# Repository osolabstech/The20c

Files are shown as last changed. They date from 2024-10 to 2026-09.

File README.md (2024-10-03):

Bienvenidos a la 20c!!!

Con cada nuevo capítulo van a poder encontrar aqui todos los archivos necesarios para crear las placas de la 20c y el código para hacer los ejemplos de uso de las mismas

Welcome to the 20c!!!

With each new chapter you will find here all the files to create the 20c pcb boards and the code to follow the examples on how to use them

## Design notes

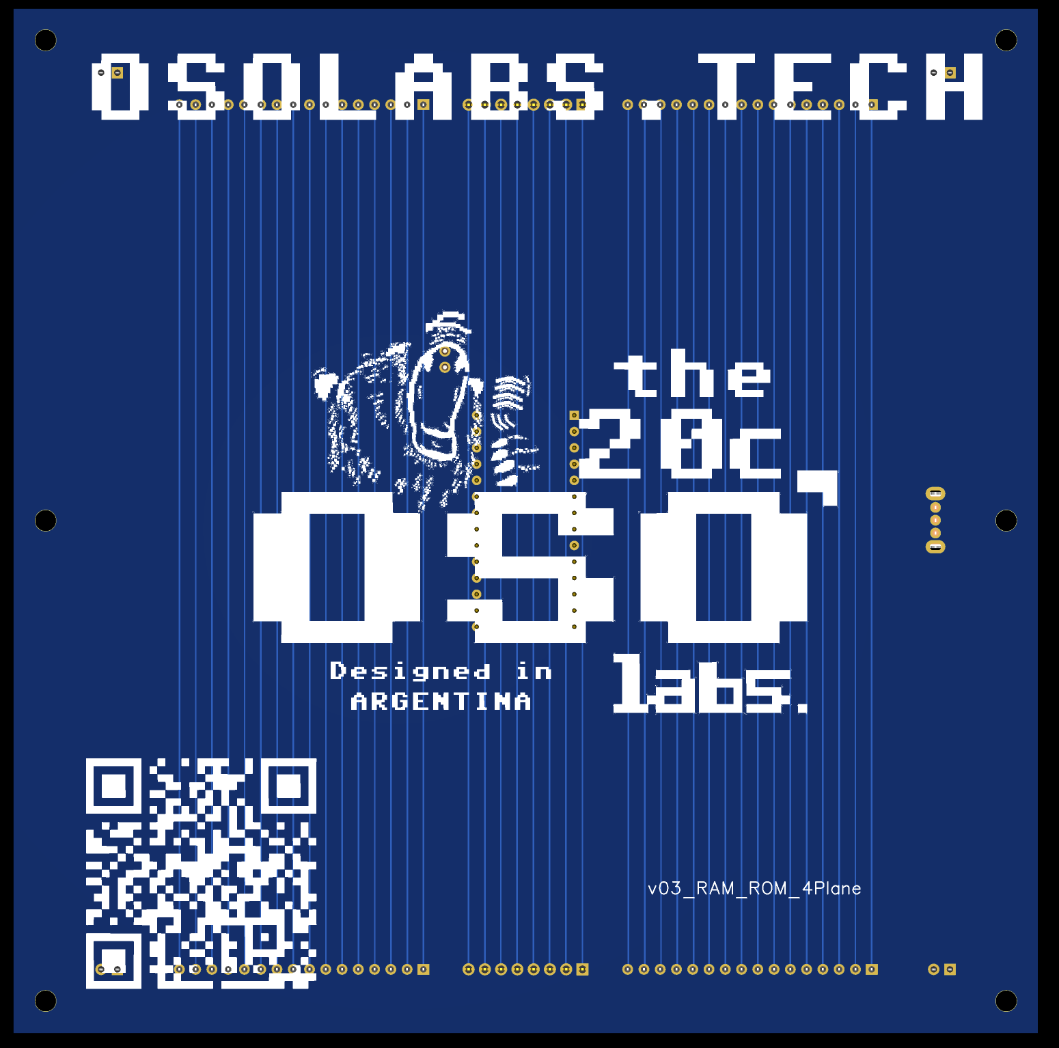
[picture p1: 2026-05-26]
Episode4_ROM/pcb/3DModel_ramrom_back.png

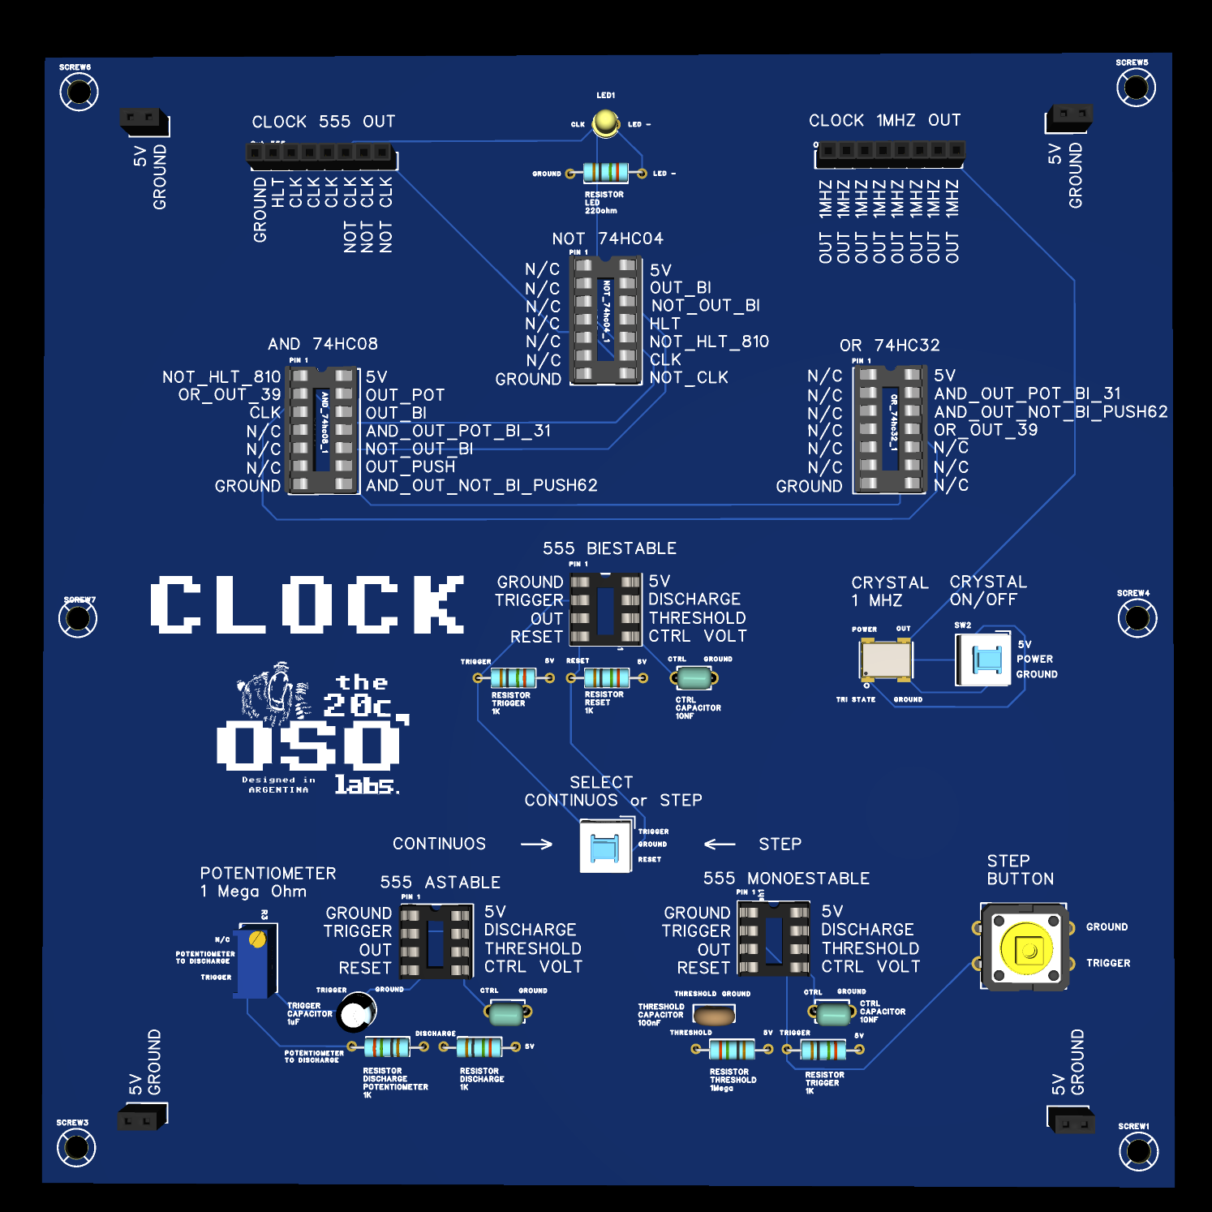
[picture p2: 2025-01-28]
Episode2_CLOCK/v03_CLOCK_4Plane/3DModel_CLOCK_FRONT.png

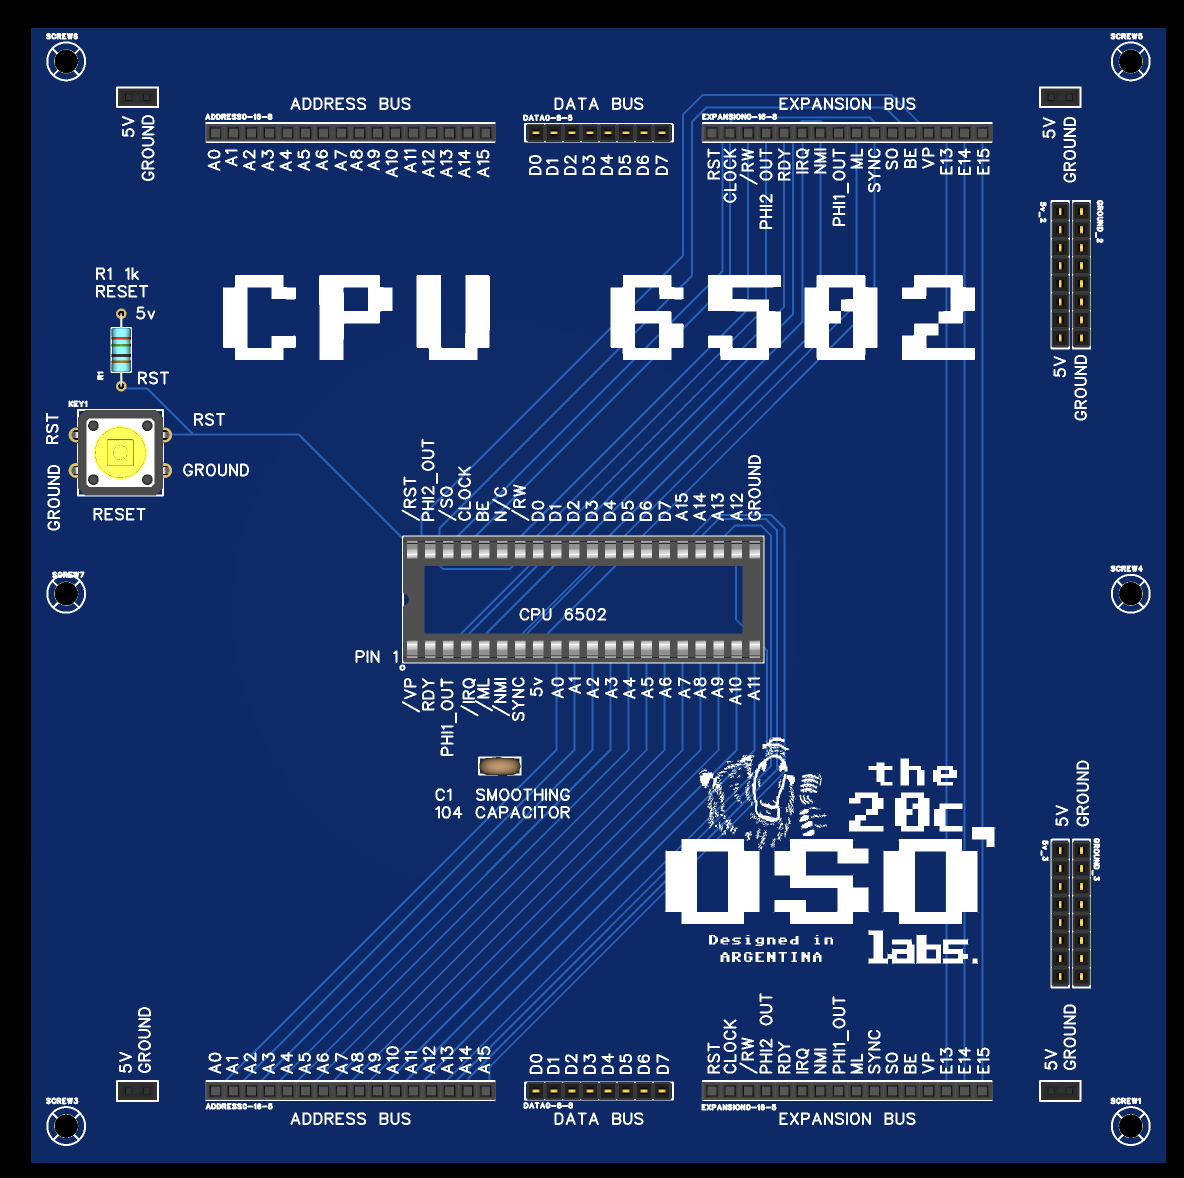
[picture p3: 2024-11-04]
Episode1_CPU6502/v03_CPU6502_4Plane/cpu6502_3dModel.png

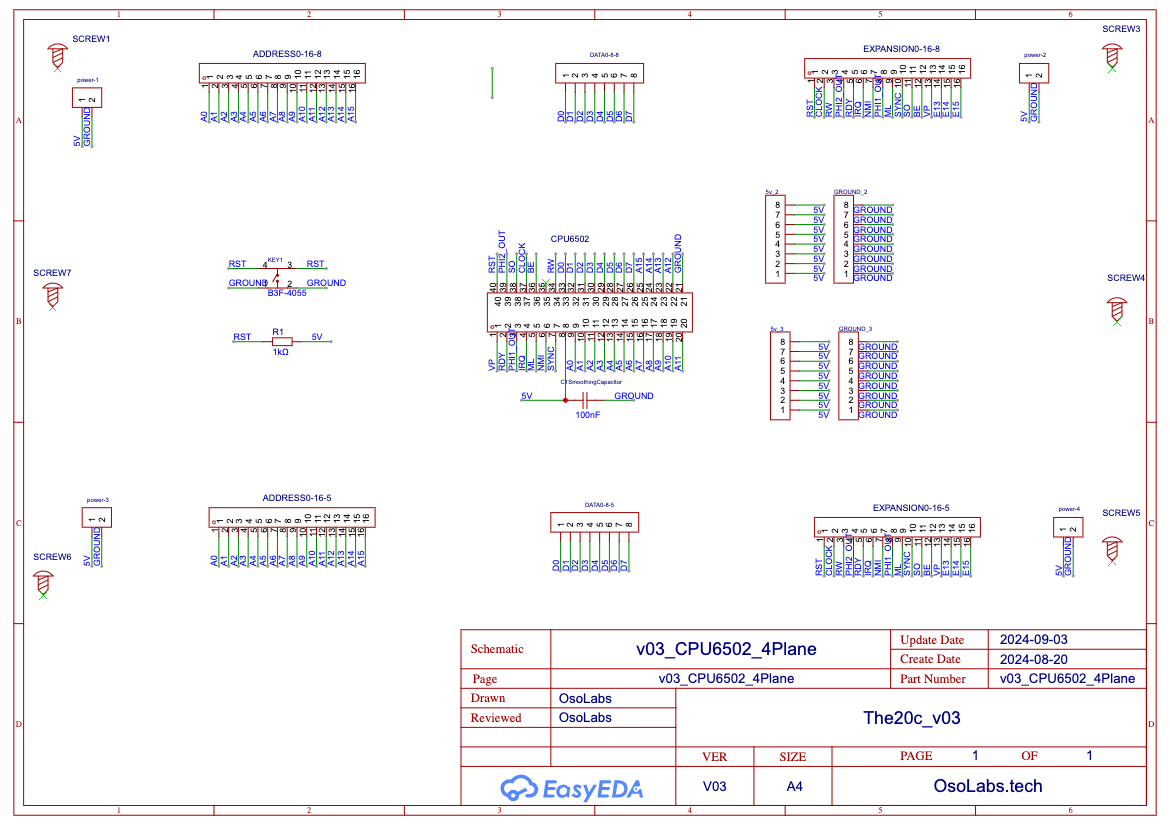
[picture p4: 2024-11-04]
Episode1_CPU6502/v03_CPU6502_4Plane/cpu6502_Circuit.png

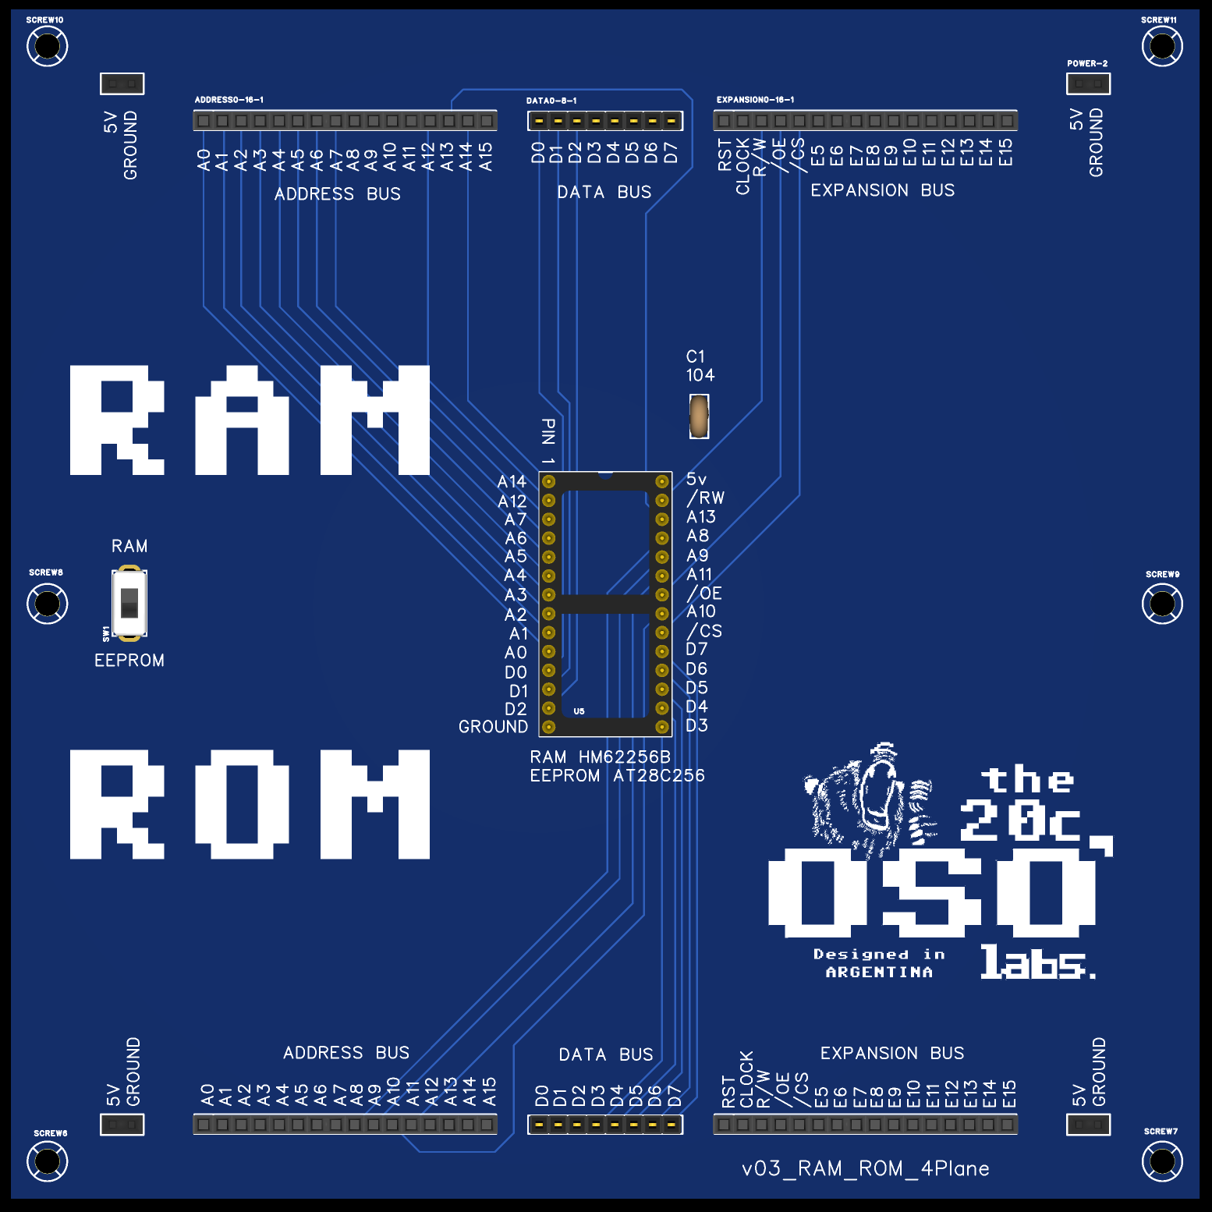
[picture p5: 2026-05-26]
Episode4_ROM/pcb/3DModel_ramrom_front.png

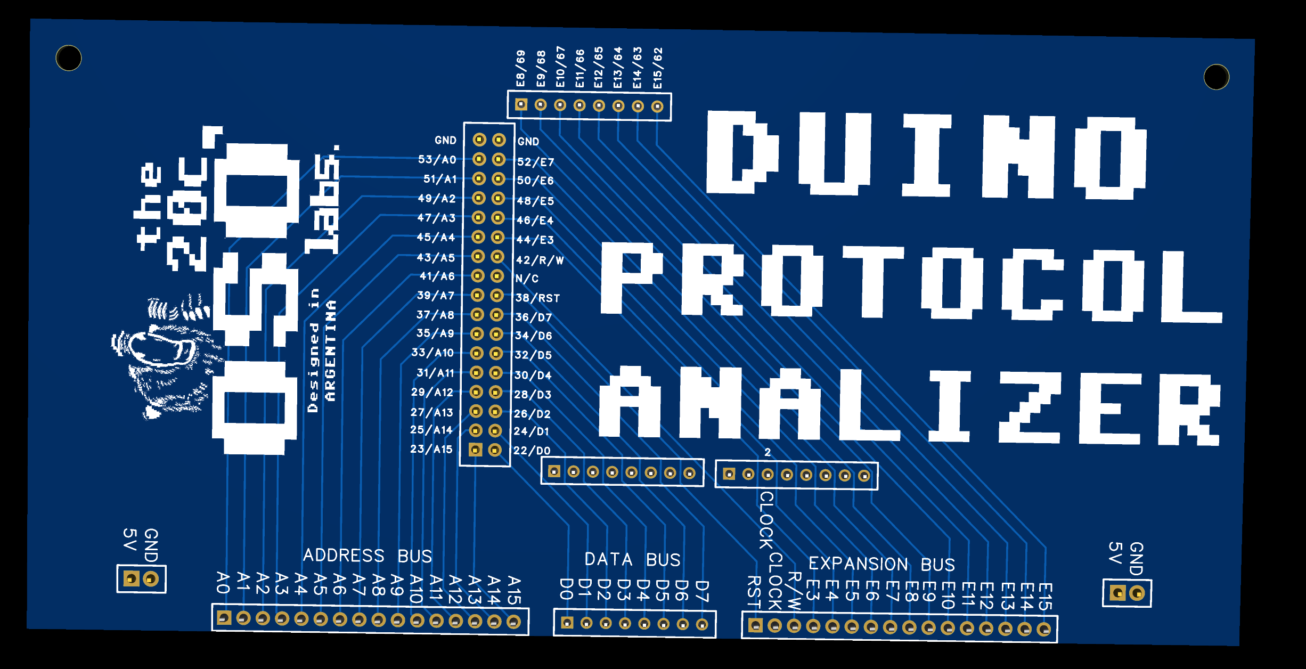
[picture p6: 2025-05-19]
Episode3_DUINO_PA/v03_PROTOCOL_ANALYZER_DUINO_4Plane/3DModel_duino_pa_back.png

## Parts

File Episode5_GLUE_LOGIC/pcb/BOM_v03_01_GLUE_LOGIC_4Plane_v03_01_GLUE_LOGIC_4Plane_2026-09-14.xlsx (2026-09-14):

No. | Quantity | Comment | Designator | Footprint | Value | Manufacturer Part | Manufacturer | Supplier Part | Supplier
1 | 12 | 2.54-1*8P母环保 | 5v_1,5v_2,5v_3,5v_4,DATA0-8-5,DATA0-8-6,DATA0-8-7,DATA0-8-8,GROUND_1,GROUND_2,GROUND_3,GROUND_4 | HDR-TH_8P-P2.54-V-F-1 |  | 2.54-1*8P母环保 | BOOMELE(博穆精密) | C27438 | LCSC
2 | 8 | PM254-1-16-Z-8.5 | ADDRESS0-16-5,ADDRESS0-16-6,ADDRESS0-16-7,ADDRESS0-16-8,EXPANSION0-16-5,EXPANSION0-16-6,EXPANSION0-16-7,EXPANSION0-16-8 | HDR-TH_16P-P2.54-V-F-A |  | PM254-1-16-Z-8.5 | HCTL(华灿天禄) | C2897379 | LCSC
3 | 4 | IC-14P窄 | AND_74hc08_1,NAND_74hc00_1,NOT_74hc04_1,OR_74hc32_1 | DIP-14_L17.8-W10.2-P2.54-BL |  | IC-14P窄 | BOOMELE(博穆精密) | C2325 | LCSC
4 | 12 | PM254-1-12-Z-8.5 | AND_HEADER,AND_HEADER1,AND_HEADER2,NAND_HEADER,NAND_HEADER1,NAND_HEADER2,NOT_HEADER,NOT_HEADER1,NOT_HEADER2,OR_HEADER,OR_HEADER1,OR_HEADER2 | HDR-TH_12P-P2.54-V-F |  | PM254-1-12-Z-8.5 | HCTL(华灿天禄) | C2897375 | LCSC
5 | 4 | 2.54-1*2P母 | power-1,power-2,power-3,power-4 | HDR-TH_2P-P2.54-V-F |  | 2.54-1*2P母 | BOOMELE(博穆精密) | C49661 | LCSC
6 | 6 | Screw-Hole-M3 | SCREW1,SCREW2,SCREW3,SCREW4,SCREW5,SCREW6 | Screw-Hole-M3

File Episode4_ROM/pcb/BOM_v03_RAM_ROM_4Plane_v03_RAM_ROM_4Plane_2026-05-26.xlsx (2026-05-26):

No. | Quantity | Comment | Designator | Footprint | Value | Manufacturer Part | Manufacturer | Supplier Part | Supplier
1 | 4 | PM254-1-16-Z-8.5 | ADDRESS0-16-1,ADDRESS0-16-2,EXPANSION0-16-1,EXPANSION0-16-2 | HDR-TH_16P-P2.54-V-F-A |  | PM254-1-16-Z-8.5 | HCTL(华灿天禄) | C2897379 | LCSC
2 | 1 | 100nF | C1SmoothingCapacitor1 | CAP-TH_L5.8-W2.4-P2.54-D0.6 | 100nF | CC1H104ZA1ED3F5P1100 | Dersonic(德尔创) | C2832506 | LCSC
3 | 2 | 2.54-1*8P母环保 | DATA0-8-1,DATA0-8-2 | HDR-TH_8P-P2.54-V-F-1 |  | 2.54-1*8P母环保 | BOOMELE(博穆精密) | C27438 | LCSC
4 | 4 | 2.54-1*2P母 | POWER-1,POWER-2,POWER-3,POWER-4 | HDR-TH_2P-P2.54-V-F |  | 2.54-1*2P母 | BOOMELE(博穆精密) | C49661 | LCSC
5 | 6 | Screw-Hole-M3 | SCREW6,SCREW7,SCREW8,SCREW9,SCREW10,SCREW11 | Screw-Hole-M3
6 | 1 | SS12D07VG4 087 | SW1 | SW-TH_SS12D07VG4 |  | SS12D07VG4 087 | SHOU HAN(首韩) | C2939726 | LCSC
7 | 1 | DS1009-28AT1WX-0A2 | U5 | DIP-28_L35.6-W17.8-P2.54-LS15.2-BL |  | DS1009-28AT1WX-0A2 | CONNFLY | C72121 | LCSC

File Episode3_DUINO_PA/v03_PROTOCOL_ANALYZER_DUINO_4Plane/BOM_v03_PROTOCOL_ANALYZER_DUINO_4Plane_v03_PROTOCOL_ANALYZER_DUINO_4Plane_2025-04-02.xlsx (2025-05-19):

No. | Quantity | Comment | Designator | Footprint | Value | Manufacturer Part | Manufacturer | Supplier Part | Supplier
1 | 4 | X6511WV-08H-C60D30 | H1,H12,H16,H18 | HDR-TH_8P-P2.54-V-M |  | X6511WV-08H-C60D30 | XKB Connection(中国星坤) | C706880 | LCSC
2 | 2 | X6511WV-16H-C60D30 | H3,H13 | HDR-TH_16P-P2.54-V-M |  | X6511WV-16H-C60D30 | XKB Connection(中国星坤) | C725948 | LCSC
3 | 2 | X6511WV-02H-C60D30 | H6,H14 | HDR-TH_2P-P2.54-V-M |  | X6511WV-02H-C60D30 | XKB Connection(中国星坤) | C706874 | LCSC
4 | 1 | PZ254-2-17-Z-8.5 | H15 | HDR-TH_34P-P2.54-V-M-R2-C17-S2.54 |  | PZ254-2-17-Z-8.5 | HCTL(华灿天禄) | C2894978 | LCSC
5 | 2 | Screw-Hole-M3 | SCREW8,SCREW9 | Screw-Hole-M3

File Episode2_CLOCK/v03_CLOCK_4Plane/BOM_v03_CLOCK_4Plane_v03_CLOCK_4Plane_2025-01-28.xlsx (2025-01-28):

No. | Quantity | Comment | Designator | Footprint | Value | Manufacturer Part | Manufacturer | Supplier Part | Supplier
1 | 3 | DS1009-08AT1NX-0A2 | 555AstablePOT,555BistableSwitch1,555MonoStablePush1 | DIP-8_L10.2-W10.2-P2.54-LS7.6-BL |  | DS1009-08AT1NX-0A2 | CONNFLY | C72124 | LCSC
2 | 3 | IC-14P窄 | AND_74hc08_1,NOT_74hc04_1,OR_74hc32_1 | DIP-14_L17.8-W10.2-P2.54-BL |  | IC-14P窄 | BOOMELE(博穆精密) | C2325 | LCSC
3 | 1 | 100nF | C1SmoothingCapacitor2 | CAP-TH_L5.8-W2.4-P2.54-D0.6 | 100nF | CC1H104ZA1ED3F5P1100 | Dersonic(德尔创) | C2832506 | LCSC
4 | 1 | 1uF | C2 | CAP-TH_BD5.0-P2.00-D0.8-FD | 1uF | KF010M050C110A | CapXon(丰宾) | C62934 | LCSC
5 | 1 | B3F-4055 | KEY1 | KEY-TH_4P-L12.0-W12.0-P5.00-LS13.4-EH |  | B3F-4055 | OMRON(欧姆龙) | C84931 | LCSC
6 | 1 | XL-302UYD | LED1 | LED-TH_BD3.8-P2.54-FD_YELLOW |  | XL-302UYD | XINGLIGHT(成兴光) | C2895472 | LCSC
7 | 2 | 2.54-1*8P母环保 | OUT_1MHZ,Out_555 | HDR-TH_8P-P2.54-V-F-1 |  | 2.54-1*8P母环保 | BOOMELE(博穆精密) | C27438 | LCSC
8 | 4 | 2.54-1*2P母 | power-1,power-2,power-3,power-4 | HDR-TH_2P-P2.54-V-F |  | 2.54-1*2P母 | BOOMELE(博穆精密) | C49661 | LCSC
9 | 5 | 1kΩ | R1,R4,R5,R10,R12 | RES-TH_BD2.7-L6.2-P10.20-D0.4 | 1kΩ | CR1/4W-1K±5%-ST26 | VO(翔胜) | C2894606 | LCSC
10 | 1 | 220Ω | R2 | RES-TH_BD2.7-L6.2-P10.20-D0.4 | 220Ω | CR1/4W-220Ω±5%-ST26 | VO(翔胜) | C2894616 | LCSC
11 | 1 | 1MΩ | R3 | RES-ADJ-TH_3296W | 1MΩ | 3296W-1-105-8mm | BOCHEN(博晨) | C330438 | LCSC
12 | 1 | 1MΩ | R9 | RES-TH_BD2.7-L6.2-P10.20-D0.4 | 1MΩ | CR1/4W-1M±5%-ST52 | VO(翔胜) | C2894664 | LCSC
13 | 6 | Screw-Hole-M3 | SCREW1,SCREW3,SCREW4,SCREW5,SCREW6,SCREW7 | Screw-Hole-M3
14 | 2 | XKB7070-Z | SW1,SW2 | SW-TH_6P-L7.0-W7.0-P2.00 |  | XKB7070-Z | XKB Connectivity(中国星坤) | C318863 | LCSC
15 | 3 | 10nF | U4,U5,U6 | CAP-TH_L4.8-W3.2-P5.08-D1.2 | 10nF | CC1H103ZC1ED3F4D1100 | Dersonic(德尔创) | C2761727 | LCSC
16 | 1 | 1MHz | X1 | OSC-SMD_4P-L7.0-W5.0-BL_7W16070003 | 1MHz | S7D1.000000A20F30T | SCTF(星通时频) | C386887 | LCSC

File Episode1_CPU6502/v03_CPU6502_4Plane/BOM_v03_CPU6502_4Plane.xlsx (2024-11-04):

No. | Quantity | Comment | Designator | Footprint | Value | Manufacturer Part | Manufacturer | Supplier Part | Supplier
1 | 6 | 2.54-1*8P母环保 | 5v_2,5v_3,DATA0-8-5,DATA0-8-8,GROUND_2,GROUND_3 | HDR-TH_8P-P2.54-V-F-1 |  | 2.54-1*8P母环保 | BOOMELE(博穆精密) | C27438 | LCSC
2 | 4 | PM254-1-16-Z-8.5 | ADDRESS0-16-5,ADDRESS0-16-8,EXPANSION0-16-5,EXPANSION0-16-8 | HDR-TH_16P-P2.54-V-F-A |  | PM254-1-16-Z-8.5 | HCTL(华灿天禄) | C2897379 | LCSC
3 | 1 | 100nF | C1SmoothingCapacitor | CAP-TH_L5.8-W2.4-P2.54-D0.6 | 100nF | CC1H104ZA1ED3F5P1100 | Dersonic(德尔创) | C2832506 | LCSC
4 | 1 | IC座-40P | CPU6502 | DIP-40_L50.8-W17.8-P2.54-LS15.2-BL |  | IC座-40P | BOOMELE(博穆精密) | C2332 | LCSC
5 | 1 | B3F-4055 | KEY1 | KEY-TH_4P-L12.0-W12.0-P5.00-LS13.4-EH |  | B3F-4055 | OMRON(欧姆龙) | C84931 | LCSC
6 | 4 | 2.54-1*2P母 | power-1,power-2,power-3,power-4 | HDR-TH_2P-P2.54-V-F |  | 2.54-1*2P母 | BOOMELE(博穆精密) | C49661 | LCSC
7 | 1 | 1kΩ | R1 | RES-TH_BD2.7-L6.2-P10.20-D0.4 | 1kΩ | CR1/4W-1K±5%-ST26 | VO(翔胜) | C2894606 | LCSC
8 | 6 | Screw-Hole-M3 | SCREW1,SCREW3,SCREW4,SCREW5,SCREW6,SCREW7 | Screw-Hole-M3

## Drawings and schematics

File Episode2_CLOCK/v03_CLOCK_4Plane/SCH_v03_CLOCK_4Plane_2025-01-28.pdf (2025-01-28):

# Adjustable Clock

# Input / Output

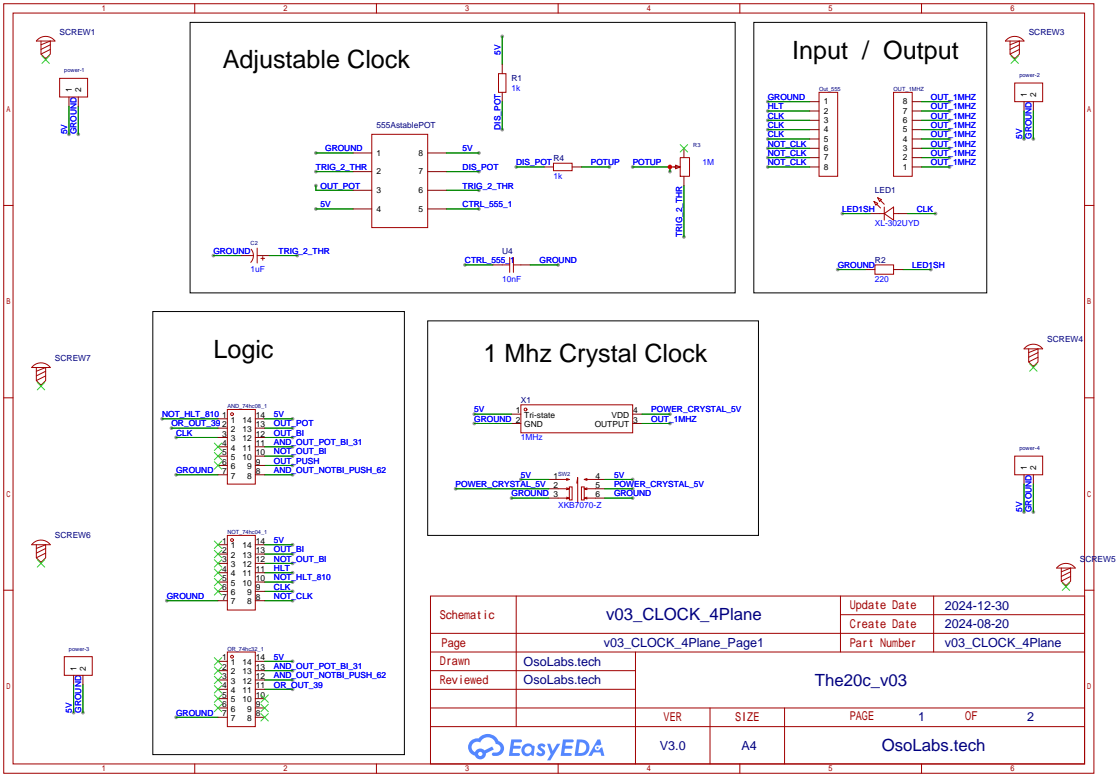
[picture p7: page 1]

Step by Step Clock | Button Debouncing

# GROUND⁵V

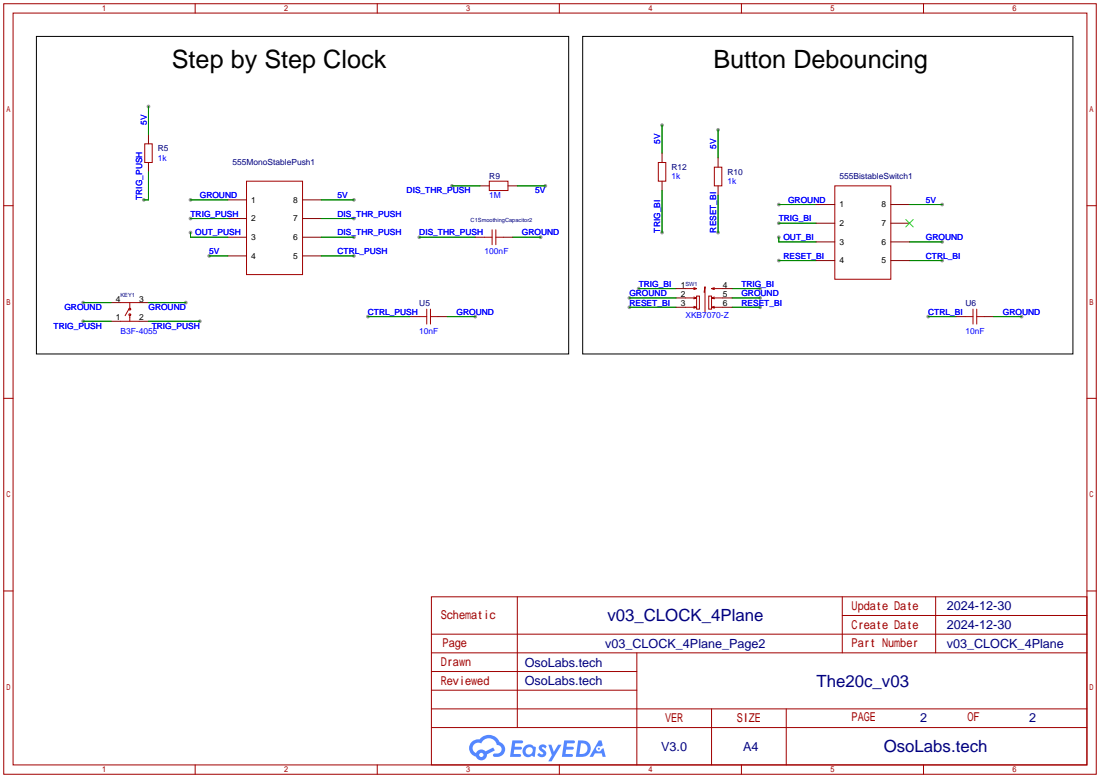
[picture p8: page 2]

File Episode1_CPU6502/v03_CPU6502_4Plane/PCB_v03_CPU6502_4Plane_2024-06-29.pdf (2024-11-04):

ADDRESS BUS | DATA BUS | EXPANSION BUS
R1 | 1k RESET

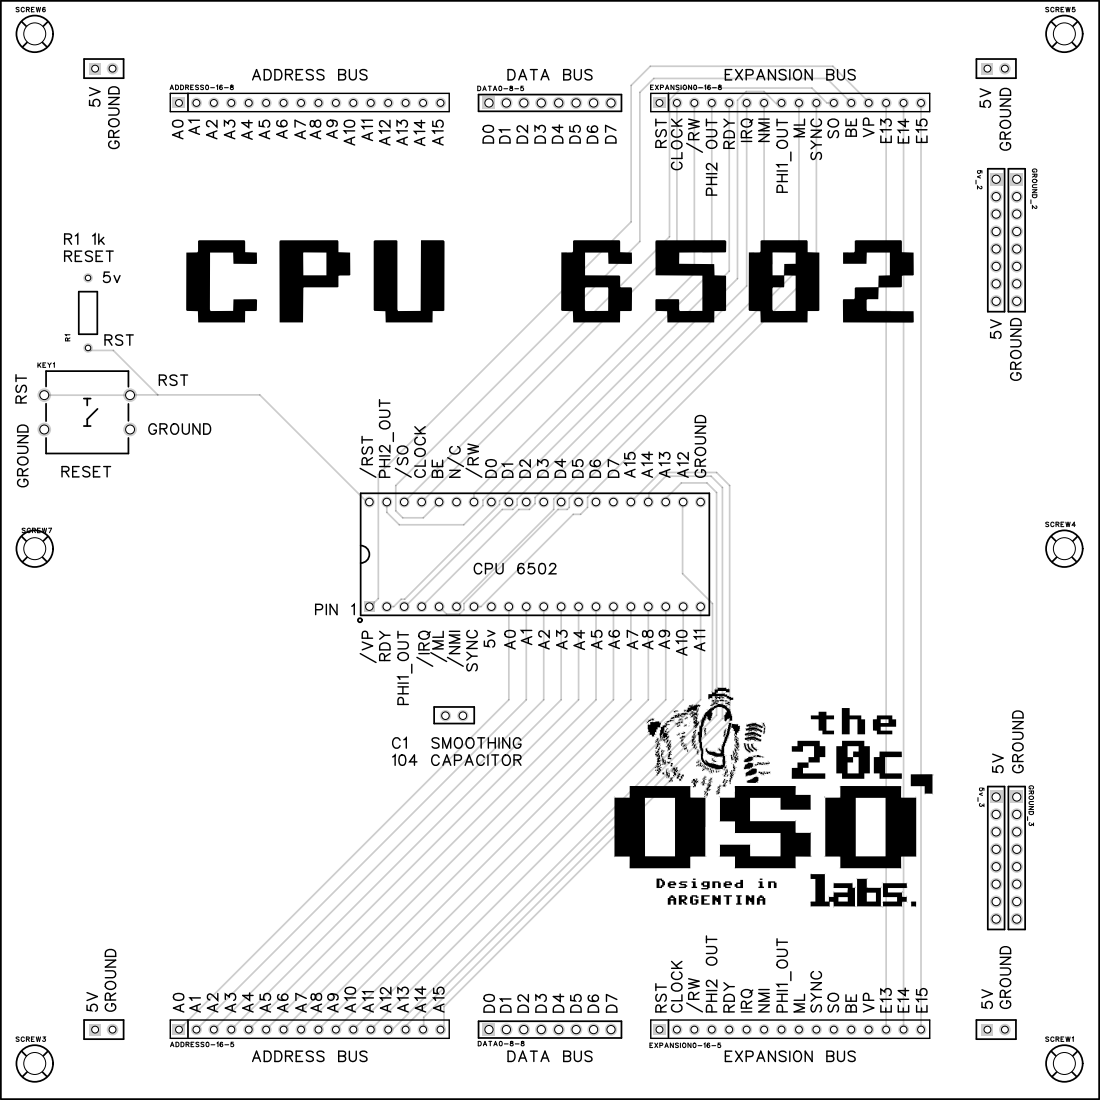
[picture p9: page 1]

RDY IRQ NMI PHI2 OUT

/VP RDY PHI1_OUT /IRQ /ML /NMI SYNC 5v /RST PHI2_OUT /SO CLOCK BEN/C /RW D0D1D2D3D4D5D6D7A15 A14 A13 A12 GROUND

RST CLOCK /RW PHI2 OUT RDY IRQ NMI PHI1_OUT MLSYNC SOBEVPE13 E14 E15

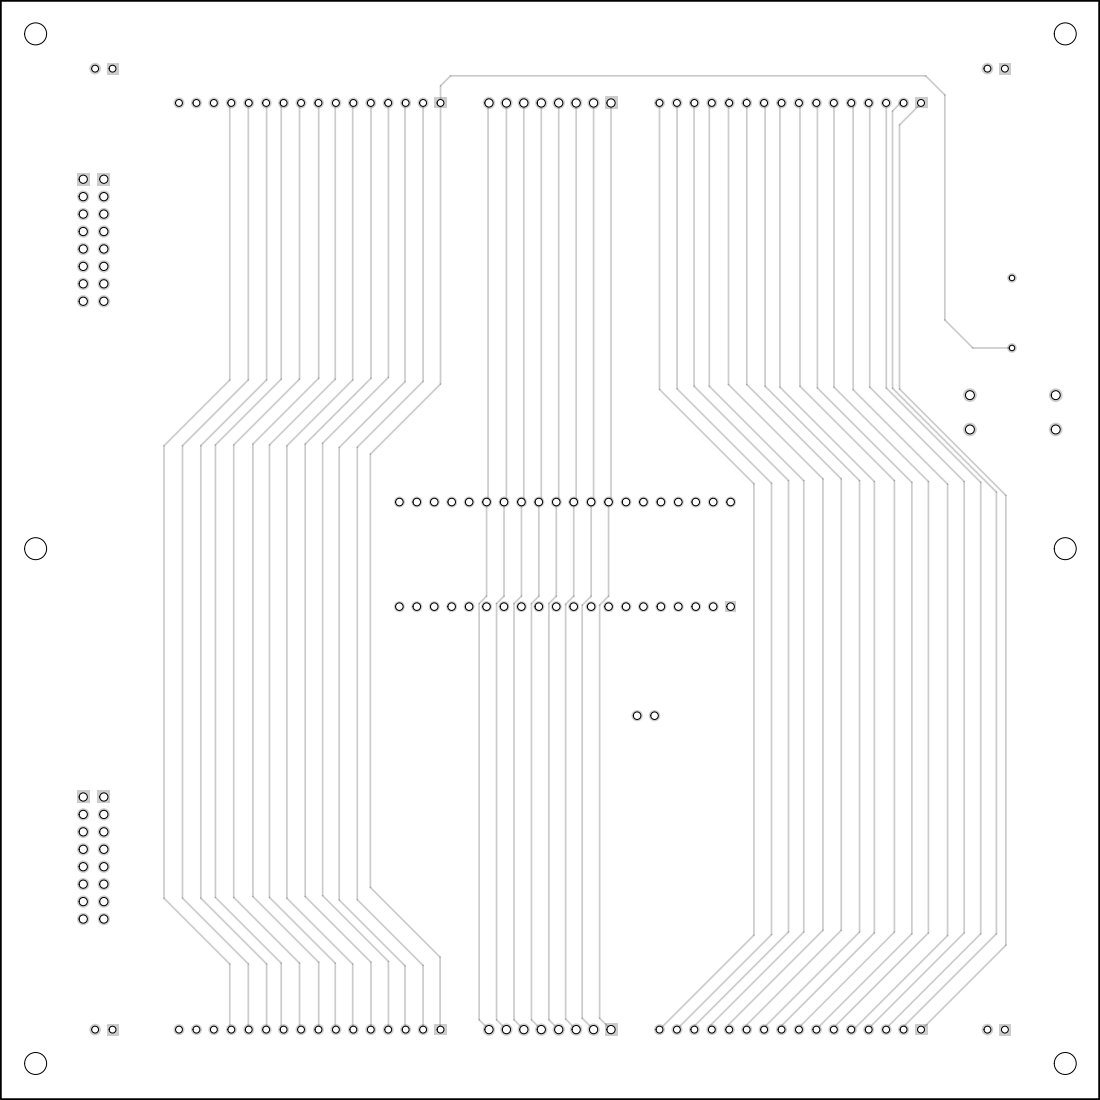
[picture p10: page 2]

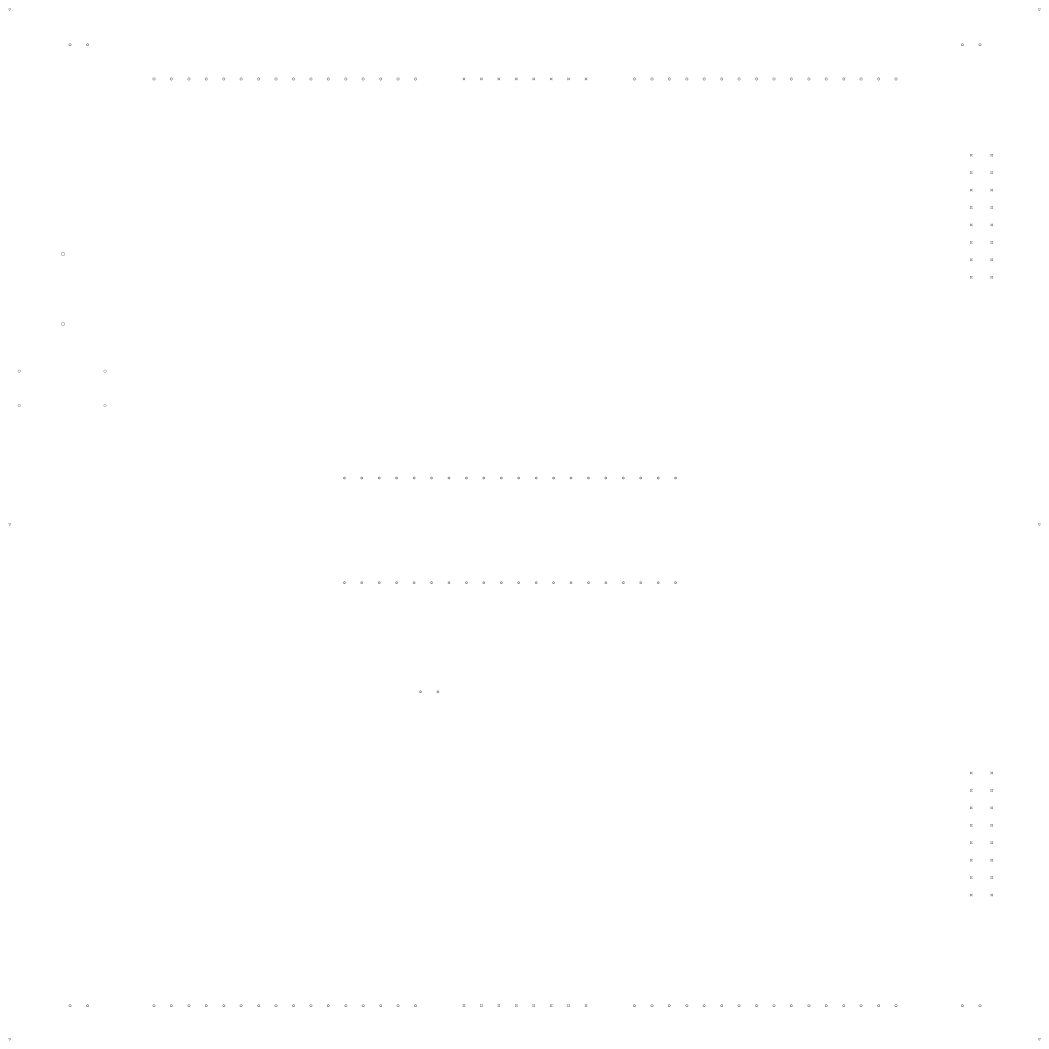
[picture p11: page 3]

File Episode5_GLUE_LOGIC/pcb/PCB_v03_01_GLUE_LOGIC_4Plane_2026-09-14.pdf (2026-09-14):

ADDRESS BUS | DATA BUS | EXPANSION BUS

# NAND HEADER

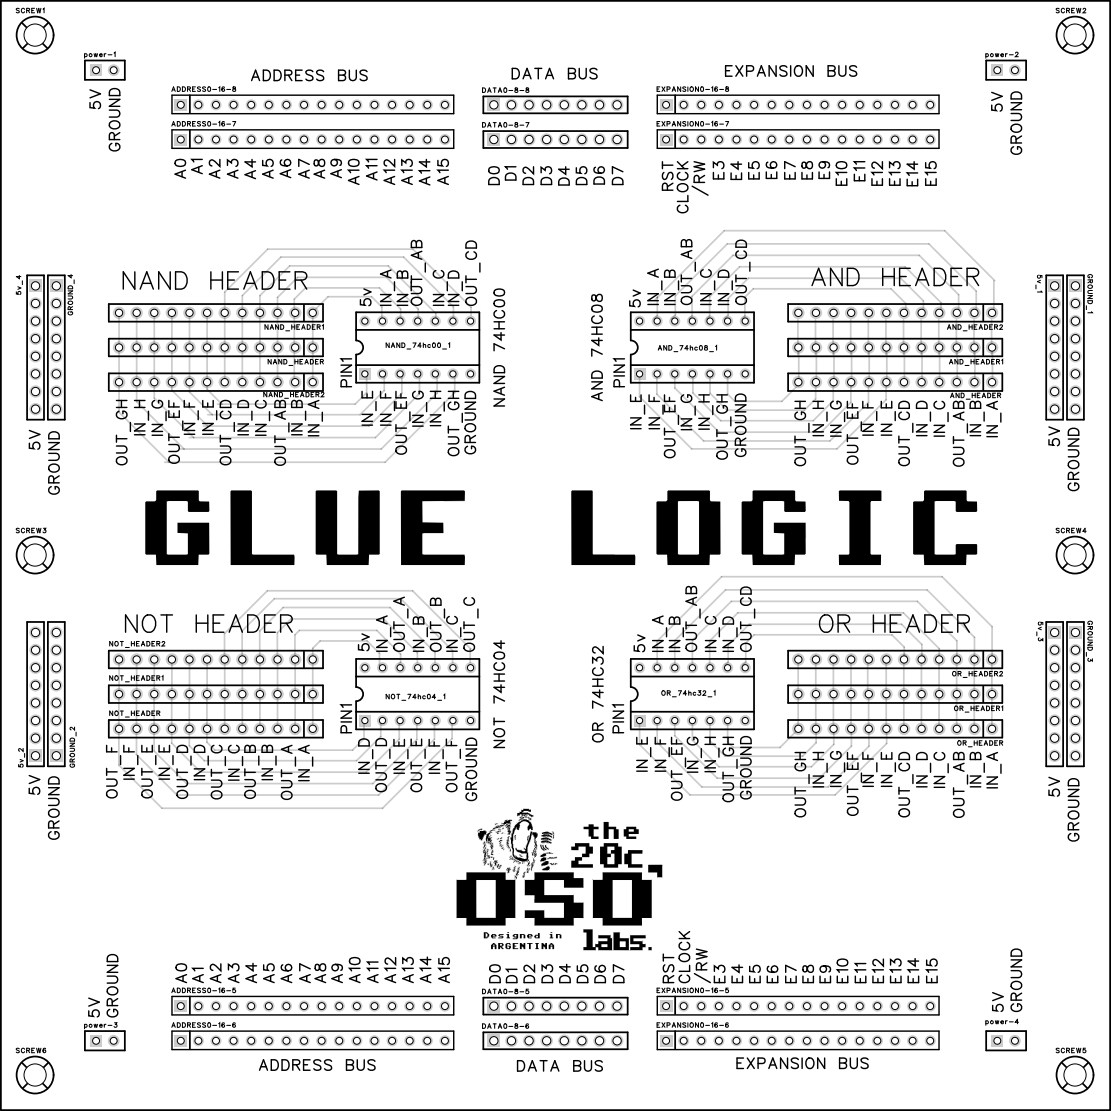
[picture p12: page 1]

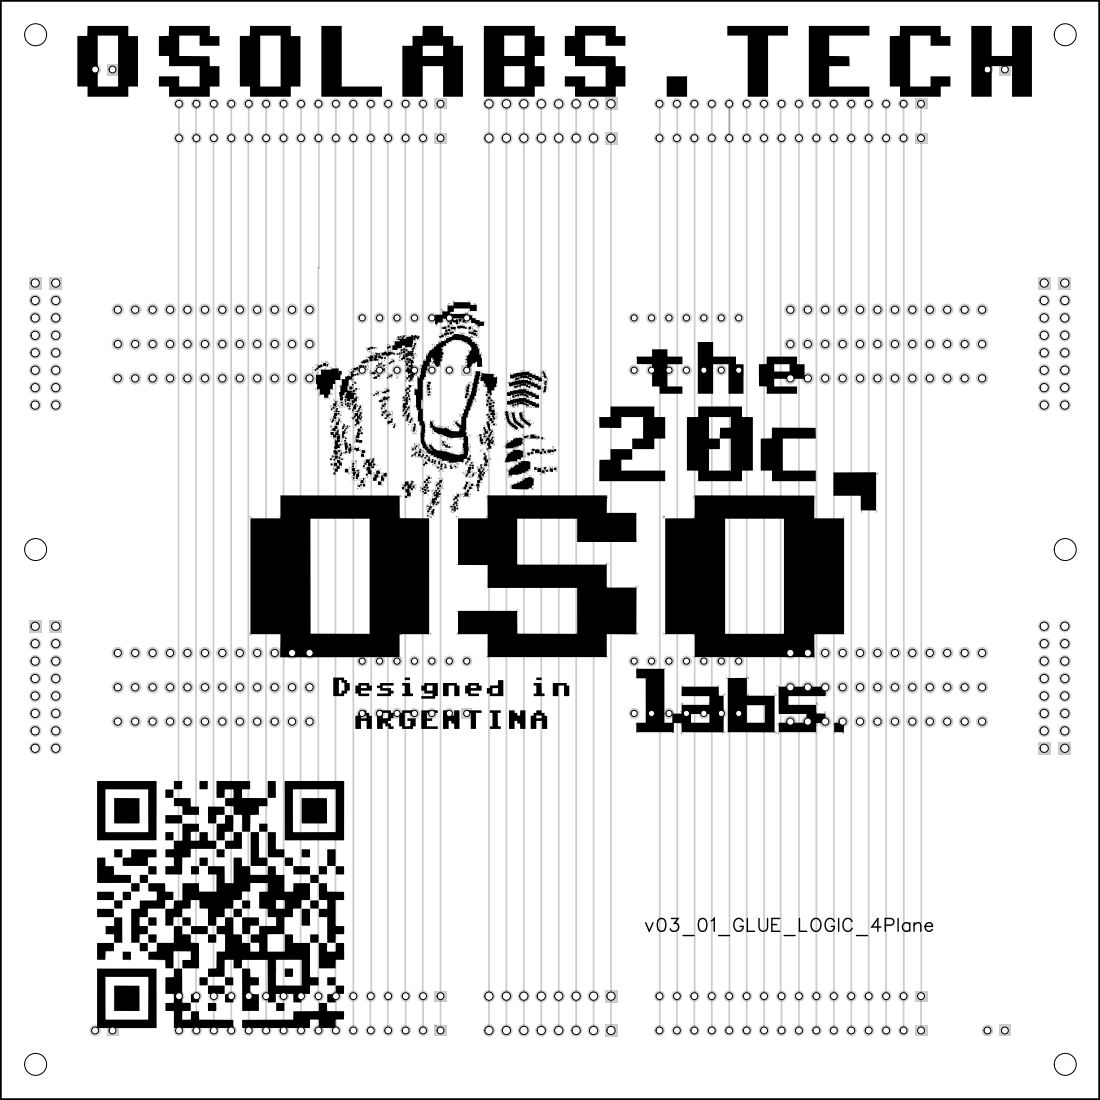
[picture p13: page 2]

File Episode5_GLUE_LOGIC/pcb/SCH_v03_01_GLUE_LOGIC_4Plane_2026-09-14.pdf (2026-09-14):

1

2

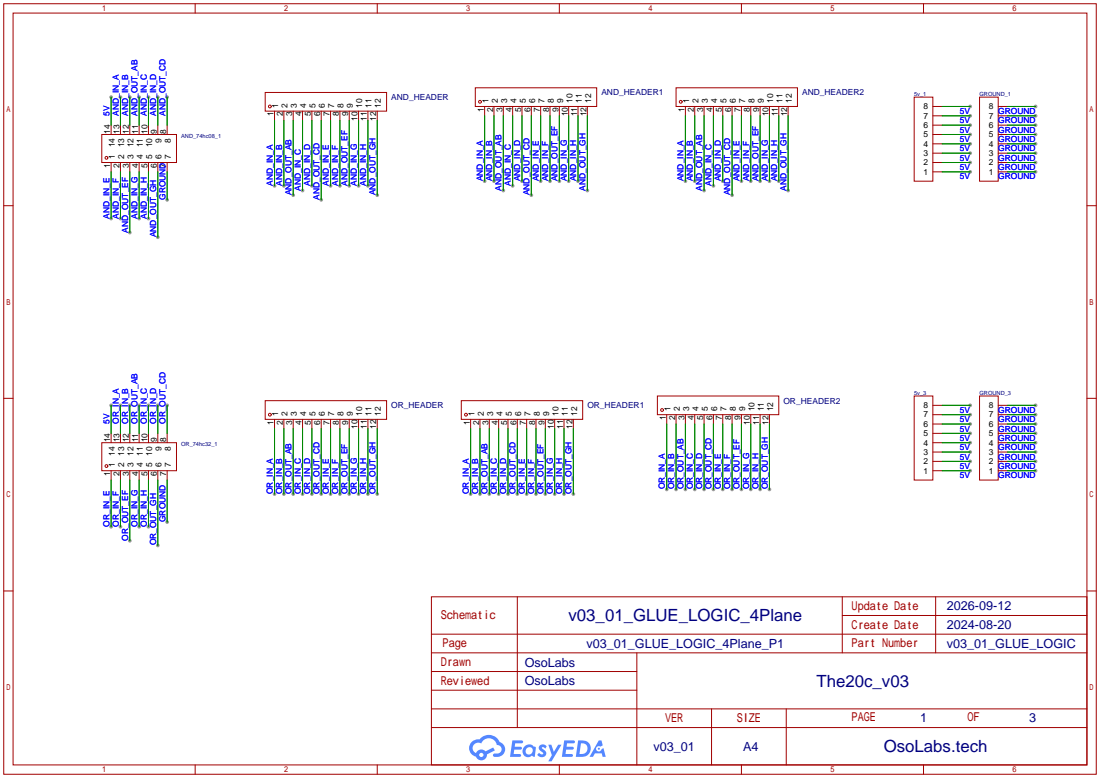
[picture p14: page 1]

# ADDRESS0-16-7 EXPANSION0-16-7

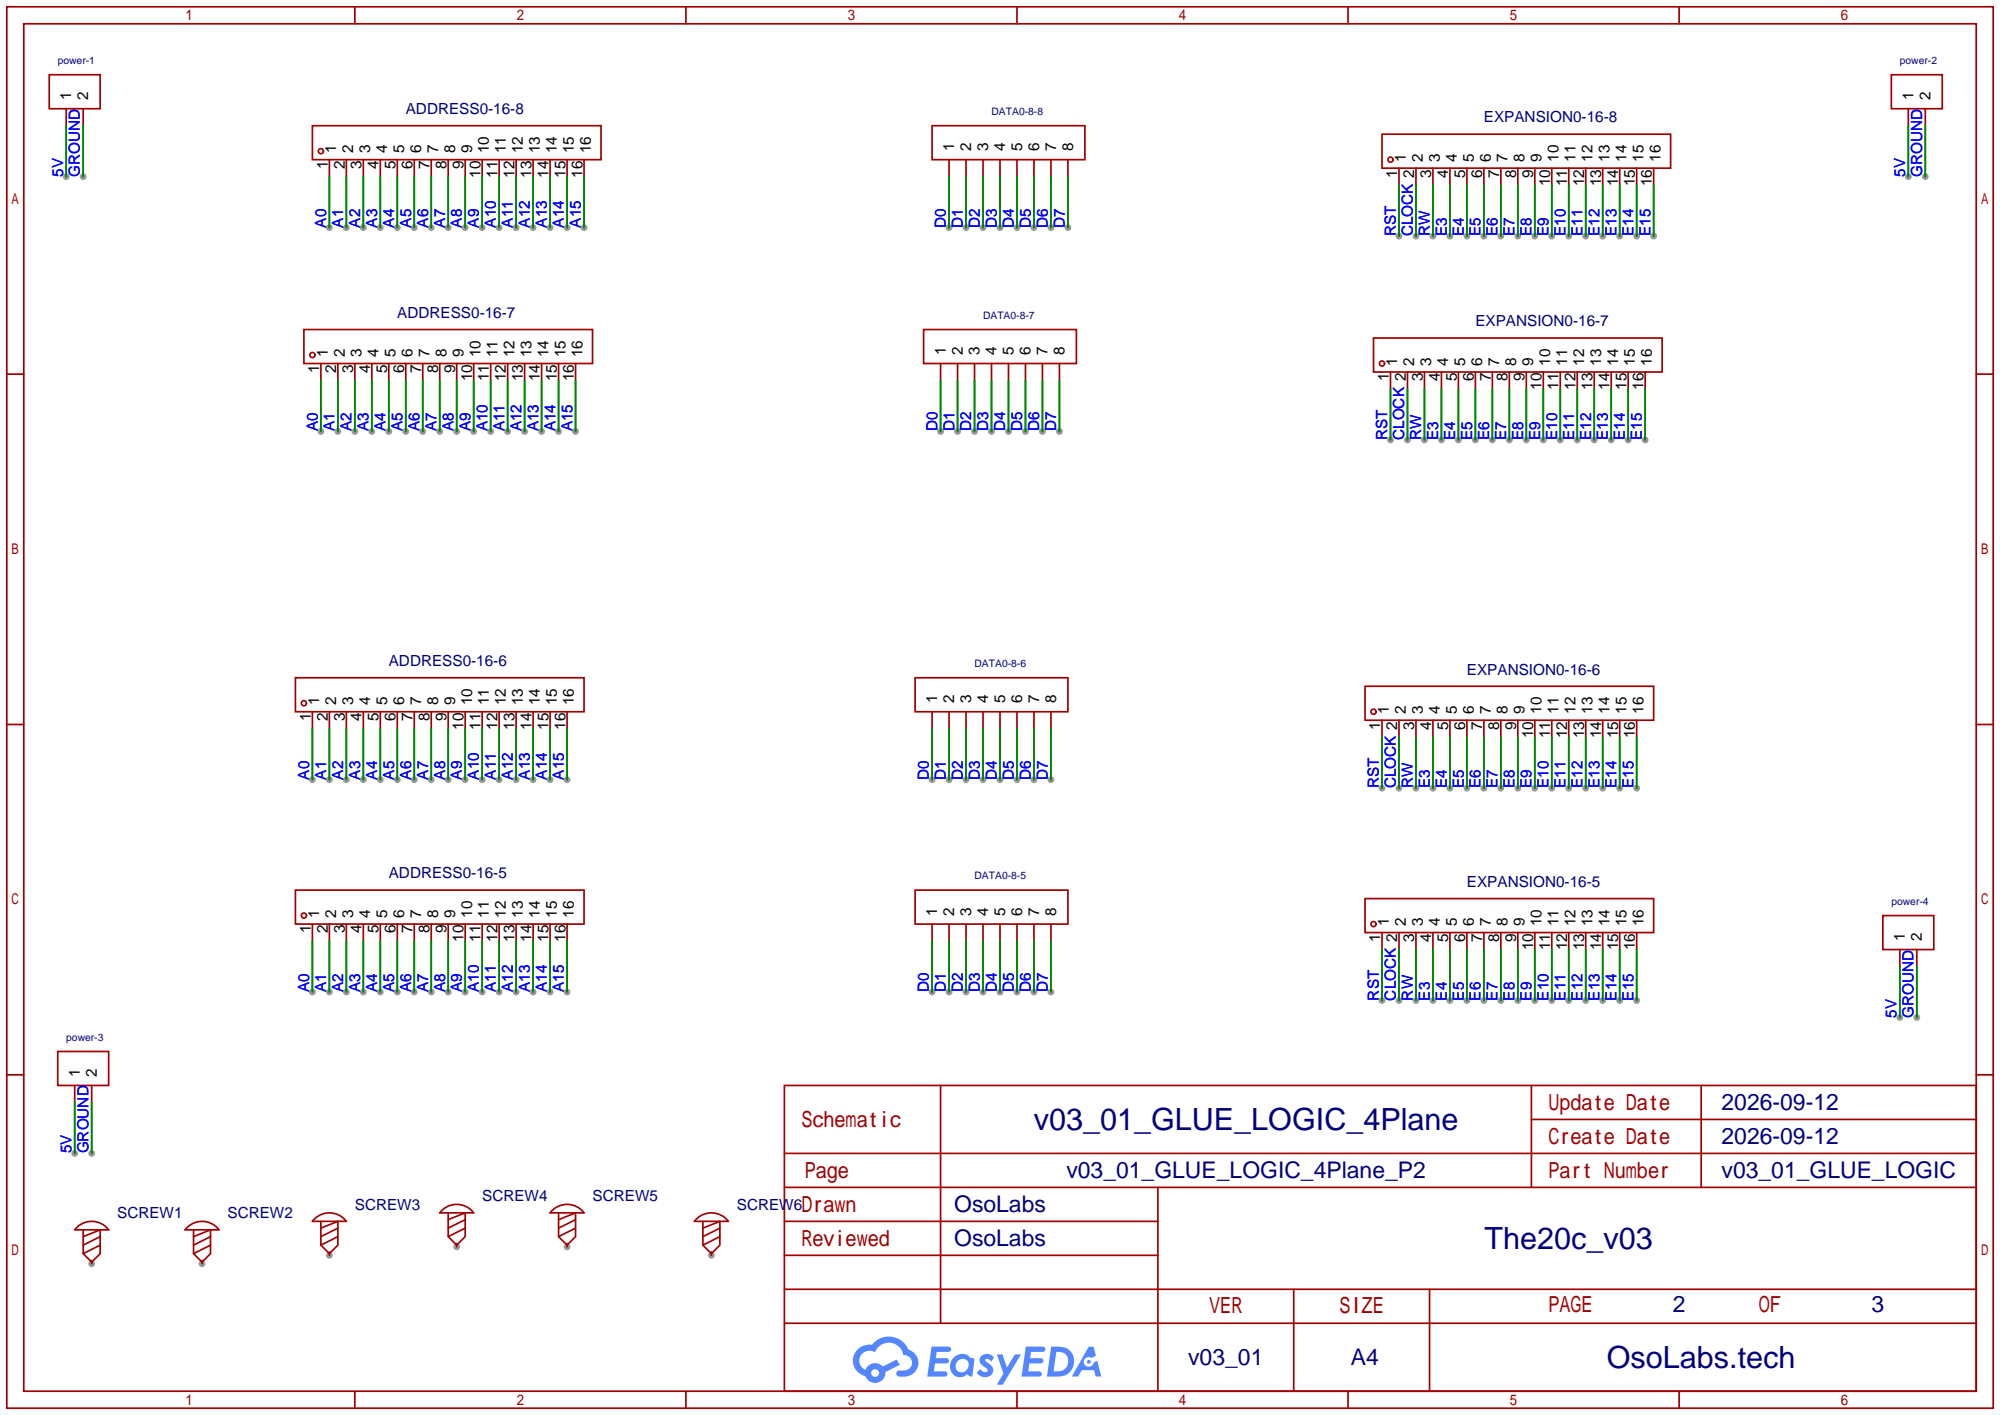
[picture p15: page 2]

# NAND_74hc00_1

# NAND_HEADER

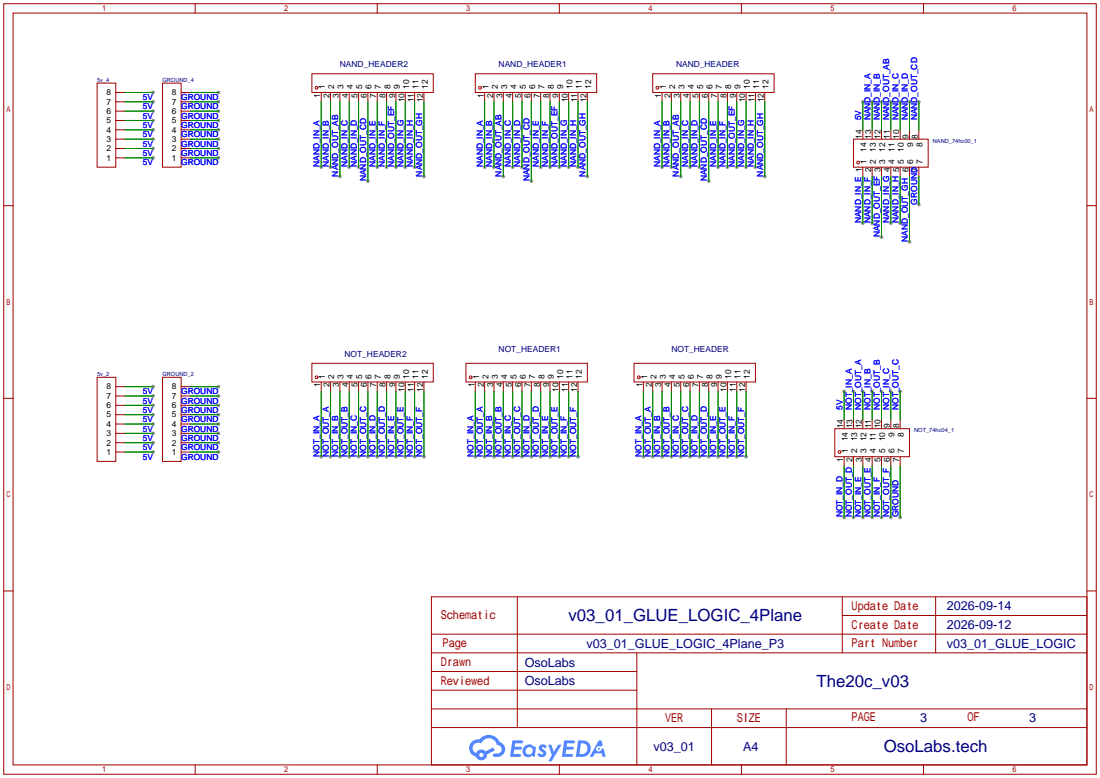
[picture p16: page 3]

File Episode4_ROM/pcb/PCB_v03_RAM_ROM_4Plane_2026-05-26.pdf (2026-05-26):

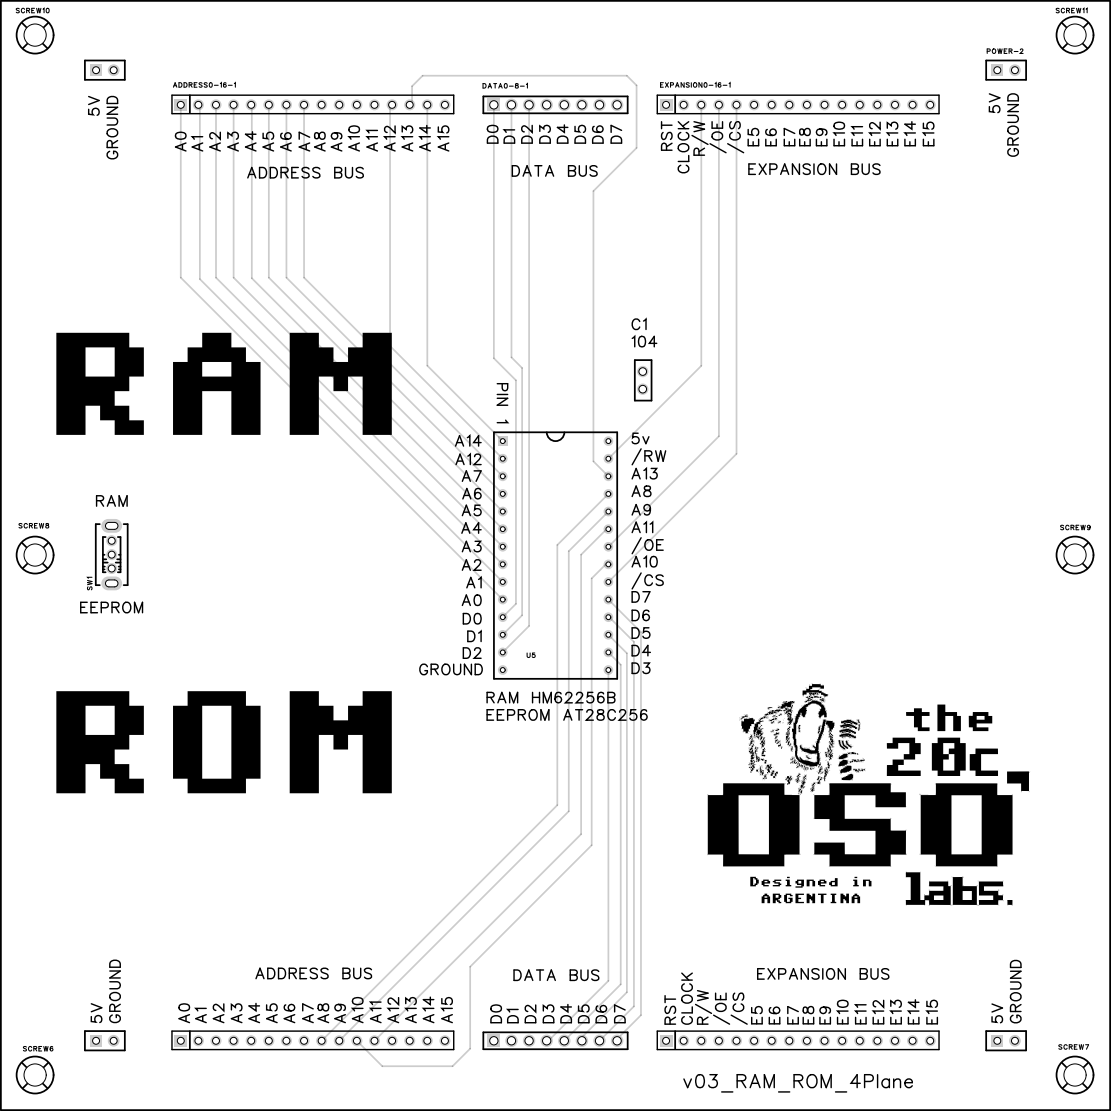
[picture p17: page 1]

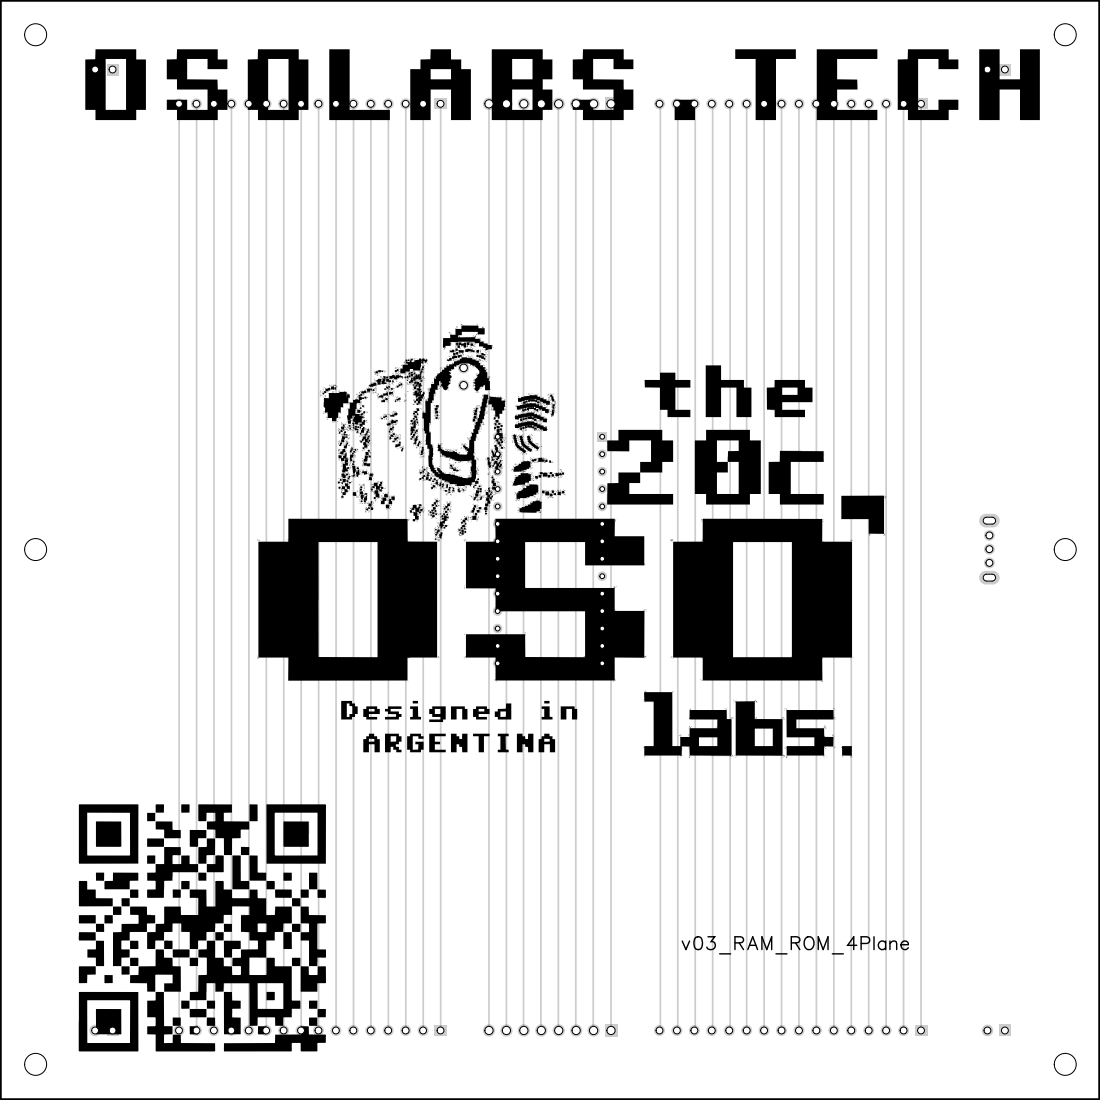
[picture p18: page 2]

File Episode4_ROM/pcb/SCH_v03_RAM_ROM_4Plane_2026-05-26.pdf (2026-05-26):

# ADDRESS0-16-1 EXPANSION0-16-1







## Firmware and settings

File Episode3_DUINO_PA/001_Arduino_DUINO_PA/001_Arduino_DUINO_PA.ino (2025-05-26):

// with DUINO PROTOCOL ANALYZER
const char ADDR[] = {23,25,27,29,31,33,35,37,39,41,43,45,47,49,51,53}; //char is one byte from -127 to 127
const char DATA[] = {36,34,32,30,28,26,24,22};
const char EXP[] = {62,63,64,65,66,67,68,69,52,50,48,46,44,42,2,38}; // pin 2 is clock because you can attach interrupts

#define RESET 38 //E0
#define CLOCK 2 //E1 40
#define READ_WRITE 42 //E2
#define SYNC 68 //E9

void setup() {
  for (int n=0;n<16;n++){
    pinMode(ADDR[n], INPUT);
    pinMode(EXP[n], INPUT);
  };
   for (int n=0;n<8;n++){
    pinMode(DATA[n], INPUT);
  };
  pinMode(CLOCK, INPUT);
  pinMode(READ_WRITE, INPUT);
  pinMode(SYNC, INPUT);
  pinMode(RESET, INPUT);
  // each time that on pin 2 (clock) i receive a HIGH on the rising edge run the onClock function
  attachInterrupt(digitalPinToInterrupt(CLOCK), onClock, RISING); 
  Serial.begin(115200);
}

void onClock (){
  char SYNC_VALUE = digitalRead(SYNC) ? 'S':'n';
  char RESET_VALUE = digitalRead(RESET) ? 'n':'R';
  char READ_WRITE_VALUE = digitalRead(READ_WRITE)?'r':'W';
  char output[40];
  unsigned int address = 0;
  for (int n=0;n<16;n++){
    int bit = digitalRead(ADDR[n]) ? 1:0; //? ternary operator if TRUE then 1 else 0
    Serial.print(bit);
    address = (address << 1) + bit;
  };
  Serial.print("    ");
  unsigned int data = 0;
  for (int n=0;n<8;n++){
    int bit = digitalRead(DATA[n]) ? 1:0; //? ternary operator if TRUE then 1 else 0
    Serial.print(bit);
    data = (data << 1) + bit;
  };
  char *instruction=sync_string(SYNC_VALUE,RESET_VALUE,data);
  char *chip=find_chip(address);
  sprintf(output, " %04x %01c %01c %02x %s %s",address,READ_WRITE_VALUE,SYNC_VALUE,data,chip,instruction);
  Serial.println(output);
}


char *sync_string(char SYNC_VALUE,char RESET_VALUE,unsigned int data) {
  if (RESET_VALUE == 'R'){
    return "RESET";
  };
  if (SYNC_VALUE == 'S'){
    switch (data){
      case 0x00:
      return "BRK";
      case 0x01:
      return "ORA X,ind";
//----------------------------CASE INSTRUCTIONS       
      case 0x02:
      return "INVALID";
      case 0x03:
      return "INVALID";
      case 0x04:
      return "INVALID";
      case 0x05:
      return "ORA zpg";
      case 0x06:
      return "ASL zpg";
      case 0x07:
      return "INVALID";
      case 0x08:
      return "PHP impl";
      case 0x09:
      return "ORA #";
      case 0x0a:
      return "ASL A";
      case 0x0b:
      return "INVALID";
      case 0x0c:
      return "INVALID";
      case 0x0d:
      return "ORA abs";
      case 0x0e:
      return "ASL abs";
      case 0x0f:
      return "INVALID";
      case 0x20:
      return "JSR abs";
//----------------------------OPCODES COMPLETE FROM HERE
      case 0x40:
      return "RTI impl";  
      case 0x41:
      return "EOR X,ind"; 
      case 0x42:
      return "INVALID";
      case 0x43:
      return "INVALID";
      case 0x44:
      return "INVALID";
      case 0x45:
      return "EOR zpg";   
      case 0x46:
      return "LSR zpg";
      case 0x47:
      return "INVALID";
      case 0x48:
      return "PHA impl";
      case 0x49:
      return "EOR #"; 
      case 0x4a:
      return "LSR A"; 
      case 0x4b:
      return "INVALID";
      case 0x4c:
      return "JMP abs";
      case 0x4d:
      return "EOR abs"; 
      case 0x4e:
      return "LSR abs";
      case 0x4f:
      return "INVALID";
      case 0x50:
      return "BVC rel";
      case 0x51:
      return "EOR ind,Y";
      case 0x52:
      return "INVALID";
      case 0x53:
      return "INVALID";
      case 0x54:
      return "INVALID";
      case 0x55:
      return "EOR zpg,X";
      case 0x56:
      return "LSR zpg,X";
      case 0x57:
      return "INVALID";
      case 0x58:
      return "CLI impl";
      case 0x59:
      return "EOR zpg,Y";
      case 0x5a:
      return "INVALID";
      case 0x5b:
      return "INVALID";
      case 0x5c:
      return "INVALID";
      case 0x5d:
      return "EOR abs,X"; 
      case 0x5e:
      return "LSR abs,X";
      case 0x5f:
      return "INVALID";
      case 0x60:
      return "RTS impl";
      case 0x61:
      return "ADC X,ind";
      case 0x62:
      return "INVALID";
      case 0x63:
      return "INVALID";
      case 0x64:
      return "INVALID";
      case 0x65:
      return "ADC zpg";
      case 0x66:
      return "ROR zpg";
      case 0x67:
      return "INVALID";
      case 0x68:
      return "PLA impl";
      case 0x69:
      return "ADC #";
      case 0x6a:
      return "ROR A";
      case 0x6b:
      return "INVALID";
      case 0x6c:
      return "JMP ind";
      case 0x6d:
      return "ADC abs";
      case 0x6e:
      return "ROR abs";
      case 0x6f:
      return "INVALID";
//----------------------------OPCODES COMPLETE UNTIL HERE
      case 0x78:
      return "SEI impl";
      case 0x80:
      return "INVALID";
      case 0x81:
      return "STA X,ind";
      case 0x82:
      return "INVALID";
      case 0x83:
      return "INVALID";
      case 0x84:
      return "STY zpg";
      case 0x85:
      return "STA zpg";
      case 0x86:
      return "STX zpg";
      case 0x87:
      return "INVALID";
      case 0x88:
      return "DEY impl";
      case 0x89:
      return "INVALID";
      case 0x8a:
      return "TXA impl";
      case 0x8b:
      return "INVALID";
      case 0x8c:
      return "STY abs";
      case 0x8d:
      return "STA abs";
      case 0x8e:
      return "STX abs";      
      case 0x8f:
      return "INVALID";
      case 0x90:
      return "BCC rel";
      case 0x91:
      return "STA ind,Y";
      case 0x9a:
      return "TXS impl";
      case 0xa0:
      return "LDY #";
      case 0xa1:
      return "LDA X,ind";
      case 0xa2:
      return "LDX #";
      case 0xa3:
      return "INVALID";
      case 0xa4:
      return "LDY zpg";
      case 0xa5:
      return "LDA zpg";
      case 0xa6:
      return "LDX zpg";      
      case 0xa7:
      return "INVALID";
      case 0xa8:
      return "TAY impl";
      case 0xa9:
      return "LDA #";
      case 0xaa:
      return "TAX impl";
      case 0xab:
      return "INVALID";
      case 0xac:
      return "LDY abs";
      case 0xad:
      return "LDA abs";
      case 0xae:
      return "LDX abs";
      case 0xaf:
      return "INVALID";
      case 0xb0:
      return "BCS Rel";
      case 0xb1:
      return "LDA ind,Y";
      case 0xb5:
      return "LDA zpg,X";
      case 0xb9:
      return "LDA abs,Y";
      case 0xbd:
      return "LDA abs,X";
      case 0xc0:
      return "CPY #";
      case 0xc8:
      return "INY impl";
      case 0xc9:
      return "CMP #";
      case 0xca:
      return "DEX impl";
      case 0xd0:
      return "BNE rel";
      case 0xe0:
      return "CPX #";
      case 0xe8:
      return "INX";
      case 0xea:
      return "NOP";
      case 0xee:
      return "INC abs";
      case 0xf0:
      return "BEQ rel";
      case 0xf8:
      return "SED impl";
      case 0xfa:
      return "BEQ rel";
//----------------------------DEFAULT CASE      
      default:
      return "UNKNOWN";
    };
    }
  else{
    return  "   " ;
  }
} 

char *find_chip(unsigned int prefix_address) {
  if (prefix_address >= 32768){ //8000 hex
    return "ROM  ";
   } else if (prefix_address >= 256 and prefix_address < 512){ //$0000 y $4000
    return "STACK";   
  } else if (prefix_address >= 0 and prefix_address < 16386){ //$0000 y $4000
    return "RAM  ";
 } else if (prefix_address >= 24576 and prefix_address < 28672){ //$6000 $7000
    return "VIA1 ";
 }  else if (prefix_address >= 28672 and prefix_address < 32768){//$7000 $8000
    return "VIA2 ";
 } else {
    return "UNKWO";
 };
}

void loop() {
}

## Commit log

2024-11-04 Episodio 1
    [Altium_Circuit_v03_CPU6502_4Plane.schdoc, Altium_PCB_v03_CPU6502_4Plane.pcbdoc, BOM_v03_CPU6502_4Plane.xlsx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]
2025-01-28 Episodio 2
    [Altium_Circuit_1_v03_CLOCK_4Plane_Page1.schdoc, Altium_Circuit_2_v03_CLOCK_4Plane_Page2.schdoc, BOM_v03_CLOCK_4Plane_v03_CLOCK_4Plane_2025-01-28.xlsx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]
2025-05-19 Episodio 3
    [Altium_Circuit_1_v03_02_PROTOCOL_ANALYZER_DUINO_4Plane.schdoc, BOM_v03_PROTOCOL_ANALYZER_DUINO_4Plane_v03_PROTOCOL_ANALYZER_DUINO_4Plane_2025-04-02.xlsx, PickA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]
2026-05-26 Ep4 ROM pcb circuits
    [Altium_Circuit_1_v03_RAM_ROM_4Plane.schdoc, BOM_v03_RAM_ROM_4Plane_v03_RAM_ROM_4Plane_2026-05-26.xlsx, PickAndPlace_v03_RAM_ROM_4Plane_2026-05-26.xlsx]
2026-09-14 Ep5 GLUE LOGIC pcb circuits
